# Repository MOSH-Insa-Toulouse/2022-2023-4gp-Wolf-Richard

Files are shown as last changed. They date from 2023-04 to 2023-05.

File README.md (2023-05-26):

# 2022-2023-4gp-Wolf-Richard

## General Description

One of our projects as part of our 4th year at INSA Toulouse in physical engineering is to create a measuring system for a paper and graphite based strain sensor. We must be able to measure the resistance of this sensor and send it to an android app.

To that we added some elements. One can choose the best gain setting for their sensor thanks to the digital potentiometer controlled by the nunchuk and helped by the OLED screen. The Nunchuk is here to choose the calibrated value for the digital potentiometer. Then, the resistance of the strain gauge is sent to an Android app thanks to a Bluetooth module.

## Deliverables

- PCB shield for Arduino Uno
- Arduino code
- Android APK
- Test bench and protocole used to test the sensor
- Datasheet

## Software versions

- KiCad 6.0.11-0
- Arduino 2.0.4
- MIT app inventor nb192

## PCB shield for Arduino Uno

The whole circuit can be seen in the picture below. Only the pins that are connected to the circuit are welded to the PCB.

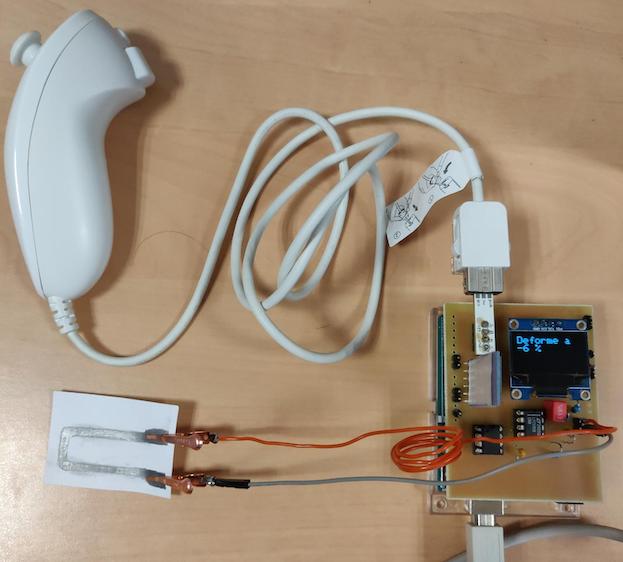
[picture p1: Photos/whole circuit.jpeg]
whole circuit


## Test Bench and protocole used to test the sensor

The test bench used is shown in the following picture.

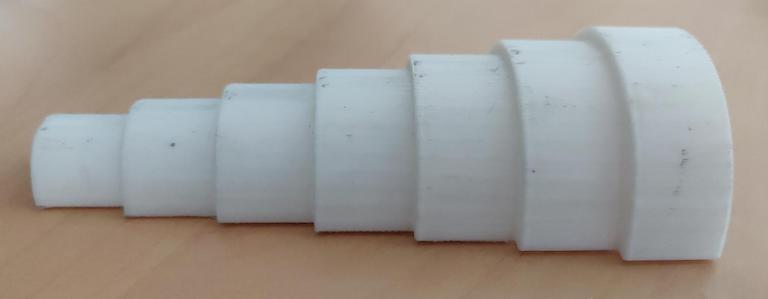
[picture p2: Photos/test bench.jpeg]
test bench


To test the sensor, we put it on the bench and try to make it take the shape of the bench as much as possible. We payed attention not to touch the graphite or the aligator clips for the test to be reliable. We took the measurments once we had a stable contact with the bench and a stable value. To determine the displacement of the sensor we used the formula:

displacement = thickness / 2*R_curvature

## User Manual of the circuit and the app

When the arduino is plugged in the program starts automatically.

First, the user needs to calibrate the circuit based on its sensor. Flatten the sensor as much as you can and try to find the best level of the potentiometer to optimise the sensor’s response. To do so, push up on the nunchuk to increase the potentiometer value or push down to decrease. When satisfied, push the C button.

Second, the user is invited to put the sensor in the most deflected position of the test that they want to do and to press C again. This allows for the deflection percentage to be shown on the OLED screen.

From that moment on, the Bluetooth module sends the value of the resistance that was calculated in the program. Thanks to the app one can retrieve the value and see its evolution.

On the app of which you can see a screenshot below, one must first connect to the right Bluetooth module with the button "Let’s go Bluetooth". Once confirmed that the connection was done properly, the toggle "Tic tac boom", which controls the clock, must be on to receive the values. The values are sent by the Bluetooth module every 500ms. The button "Send to Grisolia" saves a text file with the values of the resistance in it. It is only clickable when the clock is off.

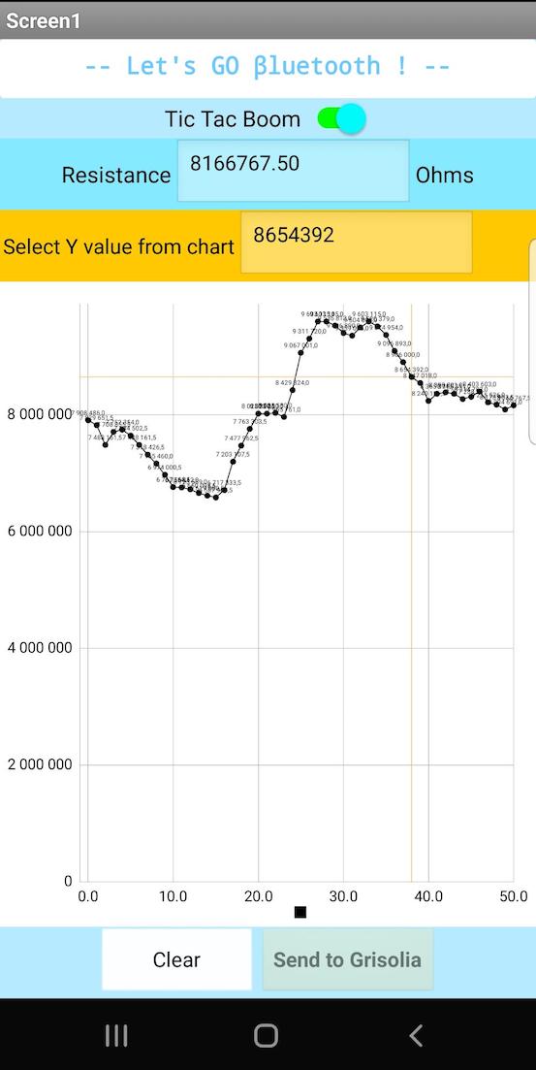
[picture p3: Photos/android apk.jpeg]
android apk


One can also select a point on the graph and see its value in the orange box. Above is displayed the value received at the moment by the app. Once a measurment done, the graph can be cleared thanks to the "Clear" button.

## Problems and improvements

We discovered too late (as the put the sheild on the Arduino) that our pin which was supposed to be connected to the +5V output pin was in fact connected to the Vin pin which delivers 4.3V. To solve that problem we cut the Vin pin and connected a cable from it to the +5V output.

We had problems using the rotary encoder, as a turn could be registered by the program even if no one had touched it. In the end, we just replaced it by the nunchuk which is much more precise and has way more functionnalities.

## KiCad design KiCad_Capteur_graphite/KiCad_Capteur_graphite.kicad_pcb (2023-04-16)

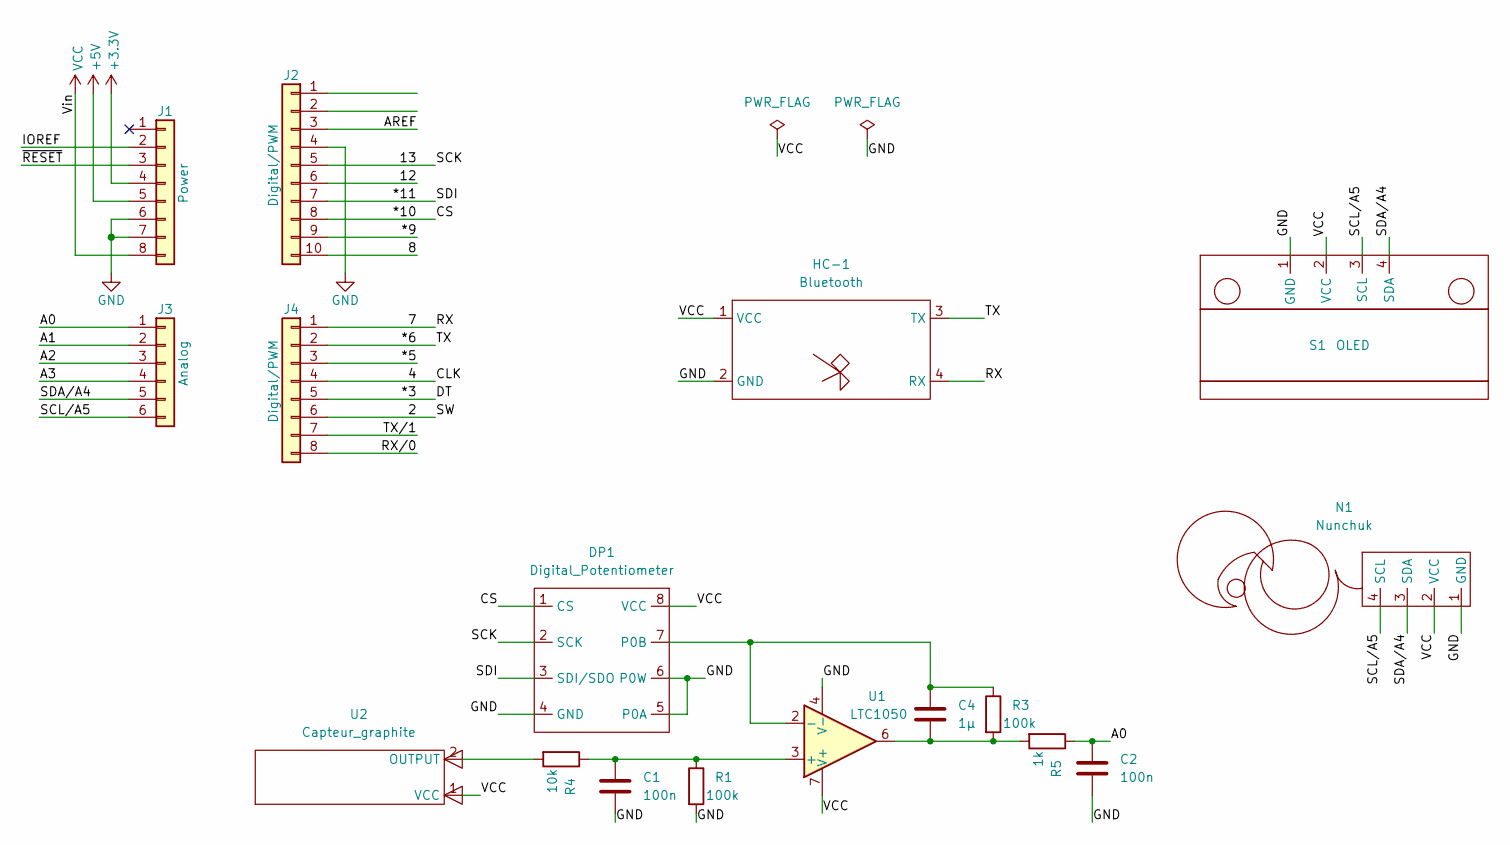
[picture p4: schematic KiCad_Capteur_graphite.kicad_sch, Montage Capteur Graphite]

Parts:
C1, C2: 100n; C_moutarde
C4: 1µ; C_rouge
DP1: Digital_Potentiometer; Digital potentimeter
HC-1: Bluetooth; Bluetooth_Empreinte
J1: Power; PinSocket_1x08_P2.54mm_Vertical
J2: Digital/PWM; PinSocket_1x10_P2.54mm_Vertical
J3: Analog; PinSocket_1x06_P2.54mm_Vertical
J4: Digital/PWM; PinSocket_1x08_P2.54mm_Vertical
N1: Nunchuk
R1, R3: 100k; R
R4: 10k; R
R5: 1k; R
S1: OLED
U1: LTC1050
U2: Capteur_graphite

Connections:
+3V3: J1.4
+5V: J1.5
/2: J4.6
/4: J4.4
/7: HC-1.4 (RX), J4.1
/8: J2.10
/12: J2.6
/13: DP1.2 (SCK), J2.5
/*3: J4.5
/*5: J4.3
/*6: HC-1.3 (TX), J4.2
/*9: J2.9
/*10: DP1.1 (CS), J2.8
/*11: DP1.3 (SDI/SDO), J2.7
/A0: C2.2, J3.1, R5.1
/A1: J3.2
/A2: J3.3
/A3: J3.4
/AREF: J2.3
/IOREF: J1.2
/RX/0: J4.8
/SCL/A5: J3.6, N1.4 (SCL), S1.3 (SCL)
/SDA/A4: J3.5, N1.3 (SDA), S1.4 (SDA)
/TX/1: J4.7
/~RESET: J1.3
GND: C1.2, C2.1, DP1.4 (GND), DP1.5 (P0A), DP1.6 (P0W), HC-1.2 (GND), J1.6, J1.7, J2.4, N1.1 (GND), R1.2, S1.1 (GND), U1.4 (V-)
unnamed: C1.1, R1.1, R4.1, U1.3 (+)
unnamed: C4.1, R3.2, R5.2, U1.6
unnamed: C4.2, DP1.7 (P0B), R3.1, U1.2 (-)
unnamed: R4.2, U2.2 (OUTPUT)
VCC: DP1.8 (VCC), HC-1.1 (VCC), J1.8, N1.2 (VCC), S1.2 (VCC), U1.7 (V+), U2.1 (VCC)

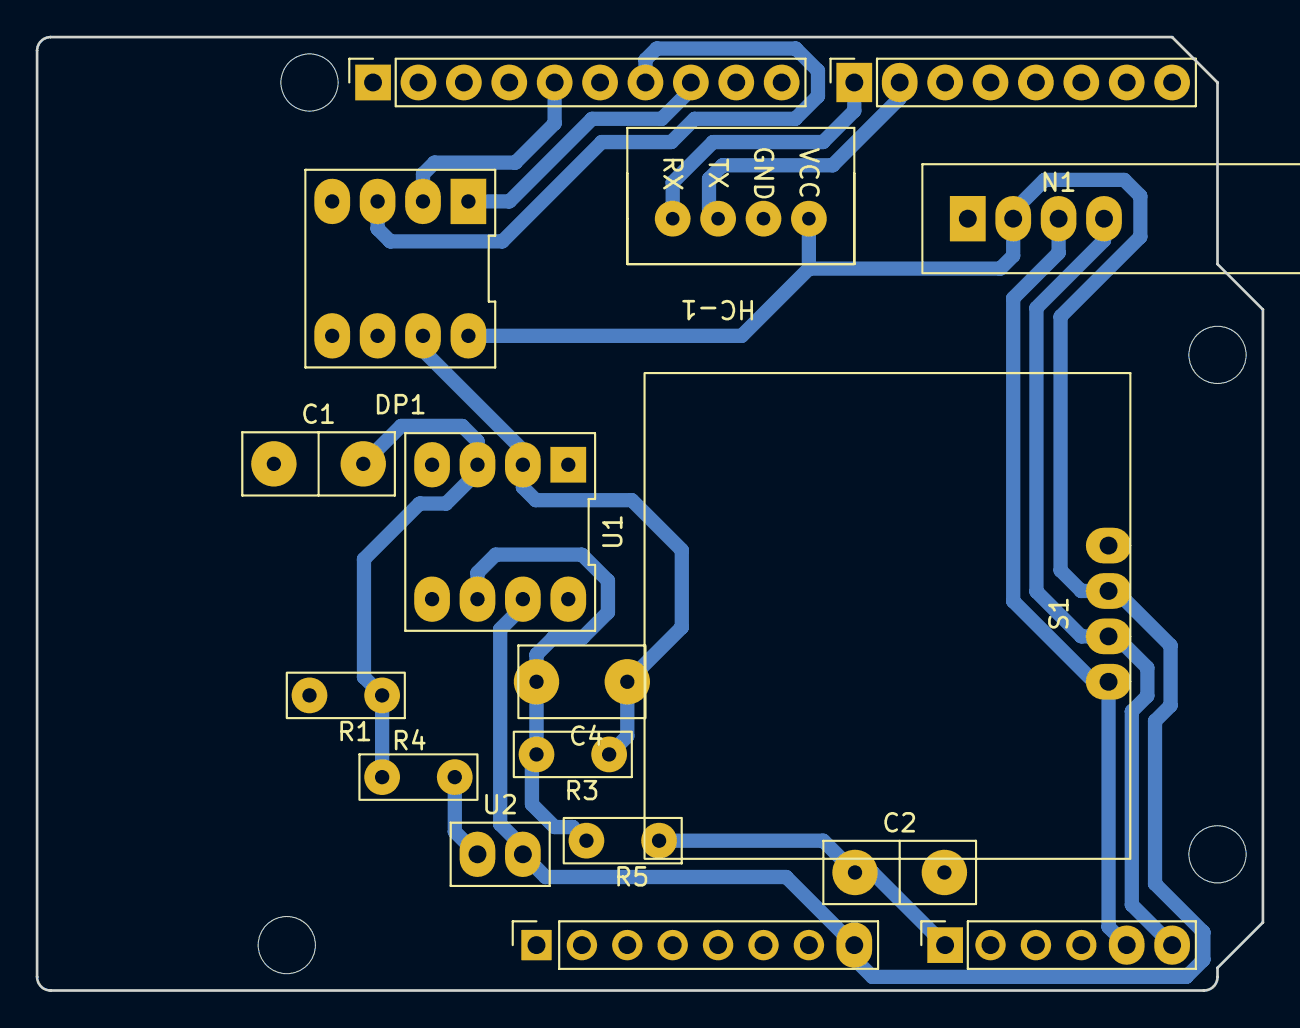
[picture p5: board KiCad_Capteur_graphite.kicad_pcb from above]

Board: 2 copper layers, 68.6 x 53.3 mm, 21 parts (0 on the bottom side), 14 nets.

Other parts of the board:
MH1, MH2, MH3, MH4: MountingHole_3.2mm

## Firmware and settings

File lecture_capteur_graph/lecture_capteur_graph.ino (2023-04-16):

//Initialisation de la communication Bluetooth
#include <SoftwareSerial.h>             // Librairie nécessaire pour communiquer avec le module bluetooth qui communique via le port série
#define rxPin 6                         // Broche 6 en tant que RXD sur le module bluetooth
#define txPin 7                         // Broche 7 en tant que TXD sur le module bluetooth
#define baudrate 9600                   // Définit la vitesse d'envoie des données entre les différents appareils
SoftwareSerial mySerial(rxPin , txPin); // Definition du software serial. On transforme les pins 6 et 7 en ports séries

//Initialisation pour l'écran OLED
#include <Adafruit_SSD1306.h>               // Librairie nécessaire pour commander le OLED qui communique via le bus I2C
#define nombreDePixelsEnLargeur 128         // Taille de l'écran OLED, en pixel, au niveau de sa largeur
#define nombreDePixelsEnHauteur 64          // Taille de l'écran OLED, en pixel, au niveau de sa hauteur
#define brocheResetOLED         -1          // Reset de l'OLED partagé avec l'Arduino (d'où la valeur à -1, et non un numéro de pin)
#define adresseI2CecranOLED     0x3C        // Adresse de "mon" écran OLED sur le bus i2c    branchement de SCL sur pinA5 et de SDA sur pinA4
Adafruit_SSD1306 ecranOLED(nombreDePixelsEnLargeur, nombreDePixelsEnHauteur, &Wire, brocheResetOLED);

//Initialisation pour le potentiomètre digital
#include <SPI.h>                      // Librairie nécessaire pour commander le potentiomètre qui communique via l'interface SPI
const byte csPin           = 10;      // Chip select pin du potentiomètre
const int  maxPositions    = 256;     // Le balayage se fait de 0 à 255 = 256 positions
const long rAB             = 44000;   // 44k résistance entre A et B, ajustée par rapport à la valeur du multimètre
const byte rWiper          = 125;     // Modifier d'un cran le potentiomètre modifie de 125 ohms la résistance
const byte pot0            = 0x11;    // Adresse du pot0 permettant de changer la valeur du potentiomètre // B 0001 0001
const byte pot0Shutdown    = 0x21;    // pot0 shutdown // B 0010 0001
int pos_pot = 13 ;                    // Position de départ du potentiomètre, proche de la position optimale pour la calibration à plat

//Initialisation pour Nunchuk
#include <Wire.h>     // Librairie nécessaire pour communiquer avec le Nunchuk qui communique via le bus I2C
#include <string.h>   //
#undef int
#include <stdio.h>
uint8_t outbuf[6];    // Matrice pour stocker les valeurs renvoyées par le nunchuk
int cnt = 0;          // Initialisation de count pour récupérer le bon nombre de bits dans la communication avec le nunchuk, voir ci-dessous
int nunchuk[2] = {0}; // Initialisation de la matrice nécessaire pour stocker l'état du bouton c et la position en y du joystick

//pour le calcul direct dans l'arduino mais pas fait pour le moment car pas d'envoie de float
float Vcc = 4.33;
float R1 = 100000.0;
//float R2 = 1000.0;              //attention R2 devient poten digital
long res_wiper = 0 ;
float R3 = 100000.0;
float R5 = 10000.0;
int min_pour = 0 ;
int max_pour = 0 ;

int calib = 0; // Indique si la calibration a été faite, calib est mise à 1 une fois la calibration réalisée

// Fonction pour commander le potentiomètre digital
/*D10           CS  (pin 1)
  D11 (MOSI)    SI  (pin 3)
  D13 (SCK)     SCK (pin 2)*/
void setPotWiper(int addr, int pos) {
  pos = constrain(pos, 0, 255);            // Limite la valeur de pos de 0 à 255
  digitalWrite(csPin, LOW);                // Selectionne le potentiomètre
  SPI.transfer(addr);                      // Donne l'adresse de l'élément dont on veut changer la valeur à pos
  SPI.transfer(pos);                       // Changement le la valeur à pos
  digitalWrite(csPin, HIGH);               // Fin de la communication avec le potentiomètre
}

// Fonctions pour le Nunchuk
void nunchuck_init()
{
  Wire.beginTransmission (0x52);  // transmit to device 0x52
  Wire.write (0x40);    // sends memory address
  Wire.write (0x00);    // sends sent a zero.
  Wire.endTransmission ();  // stop transmitting
}

void send_zero()
{
  Wire.beginTransmission (0x52);  // transmit to device 0x52
  Wire.write(0x00);   // sends one byte
  Wire.endTransmission ();  // stop transmitting
}

// Encode data to format that most wiimote drivers except
// only needed if you use one of the regular wiimote drivers
char nunchuk_decode_byte (char x)
{
  x = (x ^ 0x17) + 0x17;
  return x;
}

void print (int *output)      // Permet de retirer les valeurs qui nous intéressent uniquement, l'axe y et le bouton c
{
  int joy_y_axis = outbuf[1];
  int c_button = 0;

  // L'octet de outbuf[5] contient le bit pour le bouton c, on récupère son état grâce à un masque
  if ((outbuf[5] >> 1) & 1) {
    c_button = 1;
  }
  // Stock des valeurs utiles pour piloter les valeurs du potentiomètre, utilisé avec nunchuk dans la suite du programme
  output[0] = joy_y_axis ;
  output[1] = c_button ;
}

void setup() {
  // Setup bluetooth
  pinMode(rxPin, INPUT);
  pinMode(txPin, OUTPUT);
  mySerial.begin(baudrate);

  Serial.begin(baudrate);

  // Setup OLED
  ecranOLED.begin(SSD1306_SWITCHCAPVCC, adresseI2CecranOLED);

  // Setup du potentiomètre
  digitalWrite(csPin, HIGH);        // Chip select est par défaut déselectionné
  pinMode(csPin, OUTPUT);           // Configure le chip select comme sortie
  SPI.begin();

  // Setup nunchuk
  Wire.begin ();
  nunchuck_init ();
}

void loop() {
  // Boucle en mode calibration pour calib = 0
  // Le but des deux boucles pour calib = 0 et 1 est de pouvoir régler la sensibilité suivant le capteur que l'on a, en essayant de la maximiser par rapport à notre connaissance de notre capteur
  // Ces boucles permettent une totale adaptabilité à la résistance/conductance de notre capteur pour maximiser l'apaptabilité du circuit d'amplification
  if (calib == 0) {
    int meus = analogRead(A0);
    // Gestion de l'affichage OLED
    ecranOLED.clearDisplay();                 // Effaçage de l'intégralité du buffer
    ecranOLED.setTextSize(2);
    ecranOLED.setCursor(0, 0);
    ecranOLED.setTextColor(SSD1306_WHITE);    // Affichage du texte en "blanc" (avec la couleur principale, en fait, car l'écran monochrome peut être coloré)
    ecranOLED.println("Calib 0");
    pos_pot = constrain(pos_pot, 0, 255) ;    // Force pos_pot entre 0 et 255
    if (pos_pot == 255) {
      ecranOLED.print(meus);
      ecranOLED.println(" max");    // Si le potentiomètre est à sa valeur maximale (255), on ne peut plus l'augmenter et "max" s'affiche
    }
    else if (pos_pot == 0) {
      ecranOLED.print(meus);
      ecranOLED.println(" min");    // Si le potentiomètre est à sa valeur minimale (0), on ne peut plus la diminuer et "min" s'affiche
    }
    else {
      ecranOLED.print(meus);
      ecranOLED.print(" ");
      ecranOLED.println(pos_pot);
    }
    ecranOLED.println("Validez");
    ecranOLED.print("avec C");
    ecranOLED.display();          // Transfert le buffer à l'écran

    // Permet de piloter la valeur du potentiomètre avec les données récupérées du nunchuk
    Wire.requestFrom (0x52, 6);  // Demande les 6 octets de données du nunchuck formant un set complet de données
    while (Wire.available ()) {
      outbuf[cnt] = nunchuk_decode_byte (Wire.read());  // Convertit les octets en entiers
      cnt++;
    }
    // Si on reçoit 6 octets on en extrait les valeurs pertinentes pour notre programme que l'on stocke dans la matrice nunchuk
    if (cnt >= 5) {
      print (nunchuk);
    }
    cnt = 0;
    send_zero ();     // Demande les prochains octets

    // Conditions permettant de faire changer la valeur du potentiomètre ou de valider la calibration
    if (nunchuk[1] == 0) {
      calib = 1;        // Valide la calibration pour c appuyé, calib prend donc la valeur 1 pour sortir de la boucle de calibration
      res_wiper = ((rAB * pos_pot) / maxPositions ) + rWiper ;    // Fixe la valeur de la résistance du potentiomètre pour les calculs
      min_pour = meus ;
      nunchuk[1] = 1 ;
      delay(500) ;
    }
    if (nunchuk[0] <= 90) {
      pos_pot = pos_pot - 1 ;       // Si la valeur selon l'axe Y est inférieure à 90 (soit le joystick baissé légèrement) alors on réduit la résistance du potentiomètre
      setPotWiper(pot0, pos_pot);
    }
    if (nunchuk[0] >= 180) {
      pos_pot = pos_pot + 1 ;     // Si la valeur selon l'axe Y est supérieure à 180 (soit le joystick relevé légèrement) alors on augmente la résistance du potentiomètre
      setPotWiper(pot0, pos_pot);
    }
    delay (75);
  }
  // Cette boucle permet de sélectionner le maximum de déformation afin de pouvoir avoir une référence haute
  else if (calib == 1) {
    int meus = analogRead(A0);
    // Gestion de l'affichage OLED
    ecranOLED.clearDisplay();                 // Effaçage de l'intégralité du buffer
    ecranOLED.setTextSize(2);
    ecranOLED.setCursor(0, 0);
    ecranOLED.setTextColor(SSD1306_WHITE);    // Affichage du texte en "blanc" (avec la couleur principale, en fait, car l'écran monochrome peut être coloré)
    ecranOLED.println("Calib 100");
    ecranOLED.println(meus);
    ecranOLED.println("Validez");
    ecranOLED.print("avec C");
    ecranOLED.display();          // Transfert le buffer à l'écran

    // Permet de piloter la valeur du potentiomètre avec les données récupérées du nunchuk
    Wire.requestFrom (0x52, 6);  // Demande les 6 octets de données du nunchuck formant un set complet de données
    while (Wire.available ()) {
      outbuf[cnt] = nunchuk_decode_byte (Wire.read());  // Convertit les octets en entiers
      cnt++;
    }
    // Si on reçoit 6 octets on en extrait les valeurs pertinentes pour notre programme que l'on stocke dans la matrice nunchuk
    if (cnt >= 5) {
      print (nunchuk);
    }
    cnt = 0;
    send_zero ();     // Demande les prochains octets

    // Conditions permettant de faire changer la valeur du potentiomètre ou de valider la calibration
    if (nunchuk[1] == 0) {
      calib = 2;        // Valide la calibration pour c appuyé, calib prend donc la valeur 2 pour sortir de la deuxième boucle de calibration
      max_pour = meus ;
    }
    delay (100);
  }

  // Boucle en mode mesure une fois la calibration finie
  else if (calib == 2) {
    // On lit la valeur du capteur sur le pin A0
    int sensorValue = analogRead(A0);
    // Convertit la valeur lue (qui va de 0 à 1023) en volts (0 - 5V):
    float voltage = sensorValue * (Vcc / 1023.0);
    // Calcul de la résistance
    float res = (Vcc * R1 * (R3 + res_wiper)) / (voltage * res_wiper) - (R1 + R5);
    // Convertit la valeur du capteur en pourcentage de déformation par rapport à une plage (780 - 880) prédéfinie pour notre capteur
    int pourcentage_def = map(sensorValue, min_pour, max_pour, 0, 100) ;

    Serial.println(res);
    mySerial.print(res);                // On ecrit sur le port serie software vers le bluetooth
    ecranOLED.clearDisplay();
    ecranOLED.setTextSize(2);
    ecranOLED.setCursor(0, 0);
    ecranOLED.setTextColor(SSD1306_WHITE);
    ecranOLED.println("Deforme a");
    ecranOLED.print(pourcentage_def);
    ecranOLED.println(" %");
    ecranOLED.display();
    delay(500);
  }
}
